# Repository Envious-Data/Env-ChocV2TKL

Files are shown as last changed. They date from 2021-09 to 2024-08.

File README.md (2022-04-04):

# Env-ChocV2TKL
A Compact TKL layout utilizing Choc V2s and a Raspberry Pi Pico

### What this is
This is an experiment/concept, Ive been wanting a choc keyboard for a while but finding keycaps for choc V1s is rather difficult. There are also almost no ISO Keycap sets that would go on a TKL HOWEVER! it appears Choc V2s are more alike cherry LP switches which fit normal MX keycaps, they have a different footprint to Choc V1s and MX style switches (which Cherry LP is also not like normal MX).

###
feel free to steal the Choc V2 footprint out of here but, I made it by modifying the choc V1 footprint and just adjusted/resized a couple bits to fit but im not wholly sure if its correct.. well it should be as per the dimentions listed by Kailh.

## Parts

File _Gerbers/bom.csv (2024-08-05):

Designator | Footprint | Quantity | Value | LCSC Part #
D1, D2 | 0805 | 2 | 0805 LED
D_0, D_1, D_10, D_11, D_12, D_13, D_14, D_15, D_16, D_17, D_18, D_19, D_2, D_20, D_21, D_22, D_23, D_24, D_25, D_26, D_27, D_28, D_29, D_3, D_30, D_31, D_32, D_33, D_34, D_35, D_36, D_37, D_38, D_39, D_4, D_40, D_41, D_42, D_43, D_44, D_45, D_46, D_47, D_48, D_49, D_5, D_50, D_51, D_52, D_53, D_54, D_55, D_56, D_57, D_58, D_59, D_6, D_60, D_61, D_62, D_63, D_64, D_65, D_66, D_67, D_68, D_69, D_7, D_70, D_71, D_72, D_73, D_74, D_75, D_76, D_77, D_78, D_79, D_8, D_80, D_81, D_82, D_83, D_84, D_85, D_86, D_87, D_9 | D_SOD-123 | 88 | 1N4148W
H1, H2, H3, H4, H5, H6 | MountingHole_3.2mm_M3 | 6 | MountingHole_Pad
J1 | USB_C_TYPE-C-31-M-14 | 1 | Type-c-31-m-14
K_0, K_1, K_10, K_11, K_12, K_13, K_14, K_15, K_16, K_17, K_18, K_19, K_2, K_20, K_21, K_22, K_23, K_24, K_25, K_26, K_27, K_28, K_29, K_3, K_30, K_31, K_32, K_33, K_34, K_35, K_36, K_37, K_38, K_39, K_4, K_40, K_41, K_42, K_43, K_44, K_45, K_46, K_47, K_48, K_49, K_5, K_50, K_51, K_52, K_53, K_54, K_55, K_56, K_57, K_58, K_59, K_6, K_60, K_61, K_62, K_63, K_64, K_65, K_66, K_67, K_68, K_69, K_7, K_70, K_71, K_72, K_73, K_74, K_75, K_76, K_77, K_78, K_79, K_8, K_80, K_81, K_82, K_83, K_84, K_85, K_86, K_87, K_9 | SW_Kailh_Choc_V2 | 88 | KEYSW
R1, R2 | 0402 | 2 | 0402 470r
R5, R6 | 0805 | 2 | 5.1K 0805
RPI1 | RPi_Pico_SMD_TH_MODIFIED | 1 | Pico
SW101, SW102 | Panasonic_EVQPUL_EVQPUC | 2 | EVQPU

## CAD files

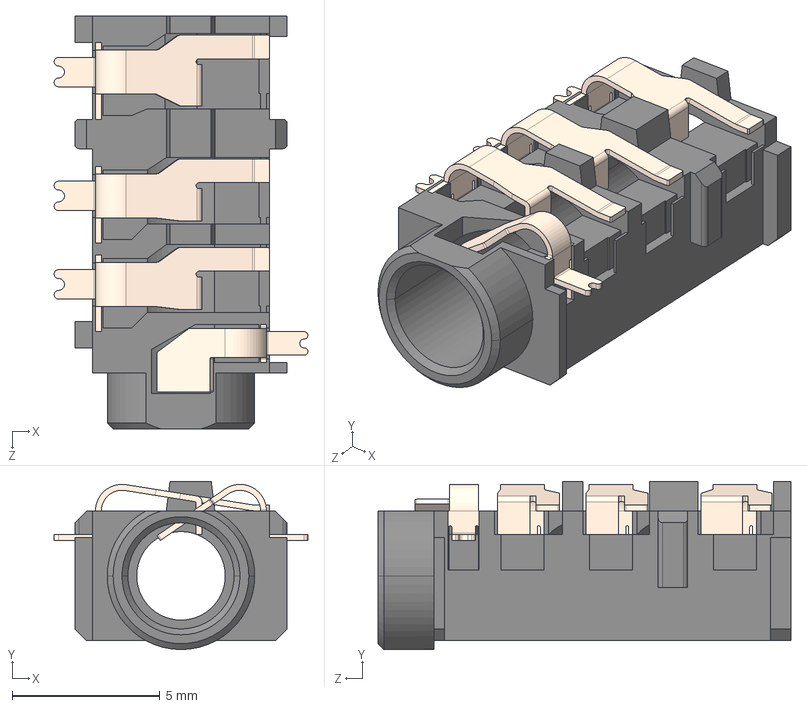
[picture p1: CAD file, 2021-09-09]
PCB Design/Footprints/Keebio-Parts.pretty-master/3dmodels/CUI_SJ-43614-SMT-TR.step
8.60 x 5.70 x 14.0 mm

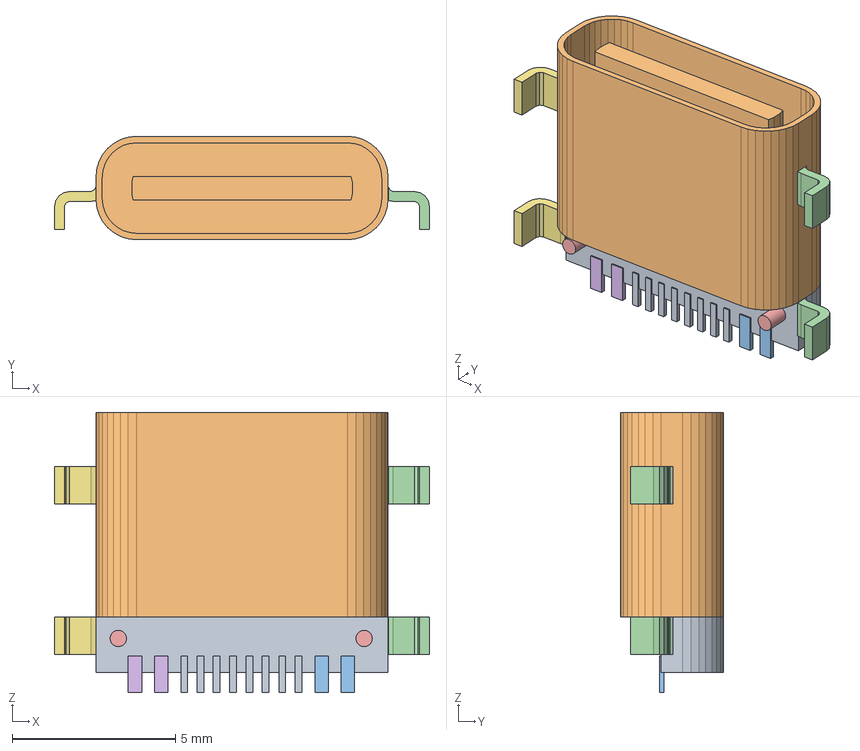
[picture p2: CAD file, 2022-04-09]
PCB Design/Footprints/TYPE-C-31-M-14.step
11.5 x 3.16 x 8.58 mm

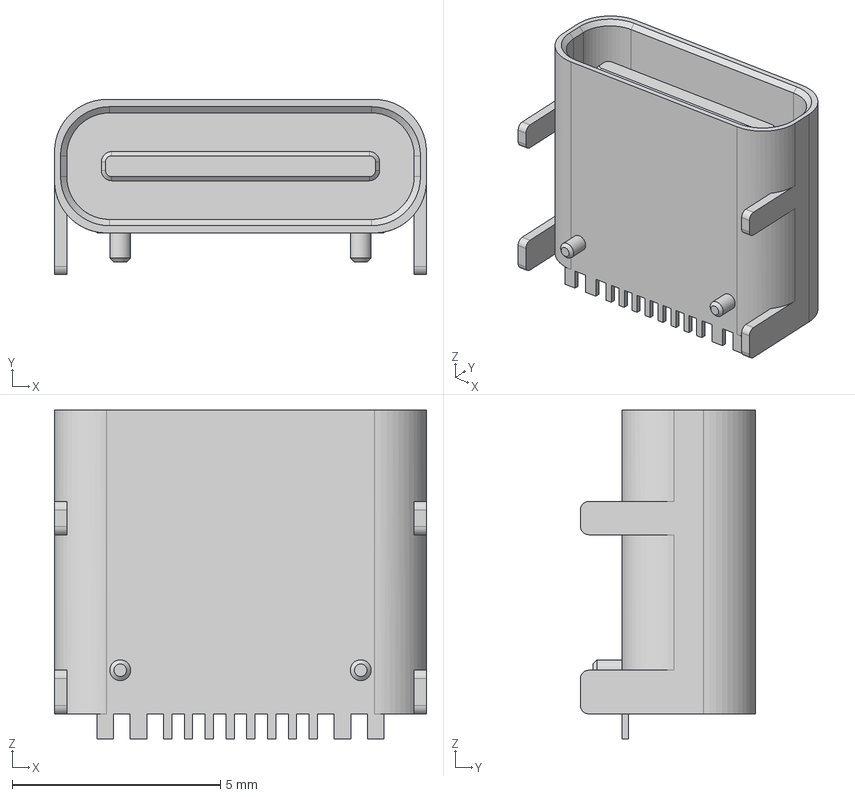
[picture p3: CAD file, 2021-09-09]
PCB Design/Footprints/Keebio-Parts.pretty-master/3dmodels/HRO TYPE-C-31-M-12.step
8.94 x 4.21 x 7.90 mm

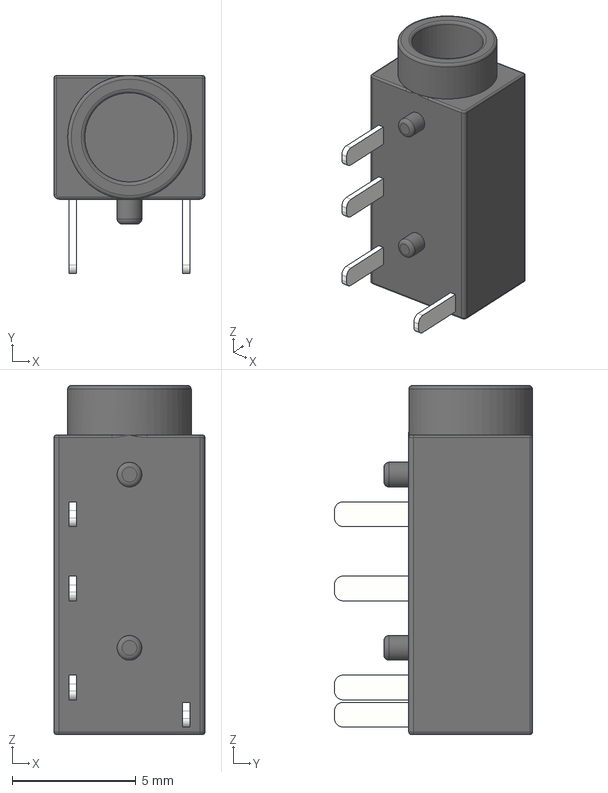
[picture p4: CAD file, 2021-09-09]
PCB Design/Footprints/Keebio-Parts.pretty-master/3dmodels/PJ-320A.step
6.10 x 8.00 x 14.1 mm

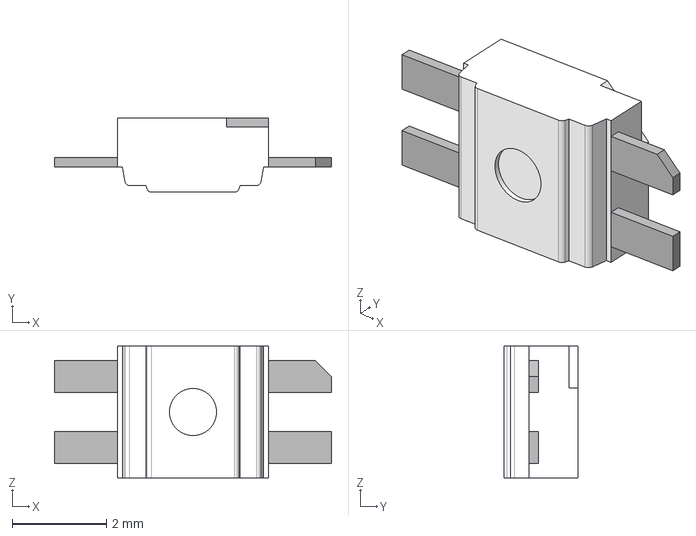
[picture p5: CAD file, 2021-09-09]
PCB Design/Footprints/Keebio-Parts.pretty-master/3dmodels/SK6812MINI-E v1.step
5.88 x 1.58 x 2.80 mm

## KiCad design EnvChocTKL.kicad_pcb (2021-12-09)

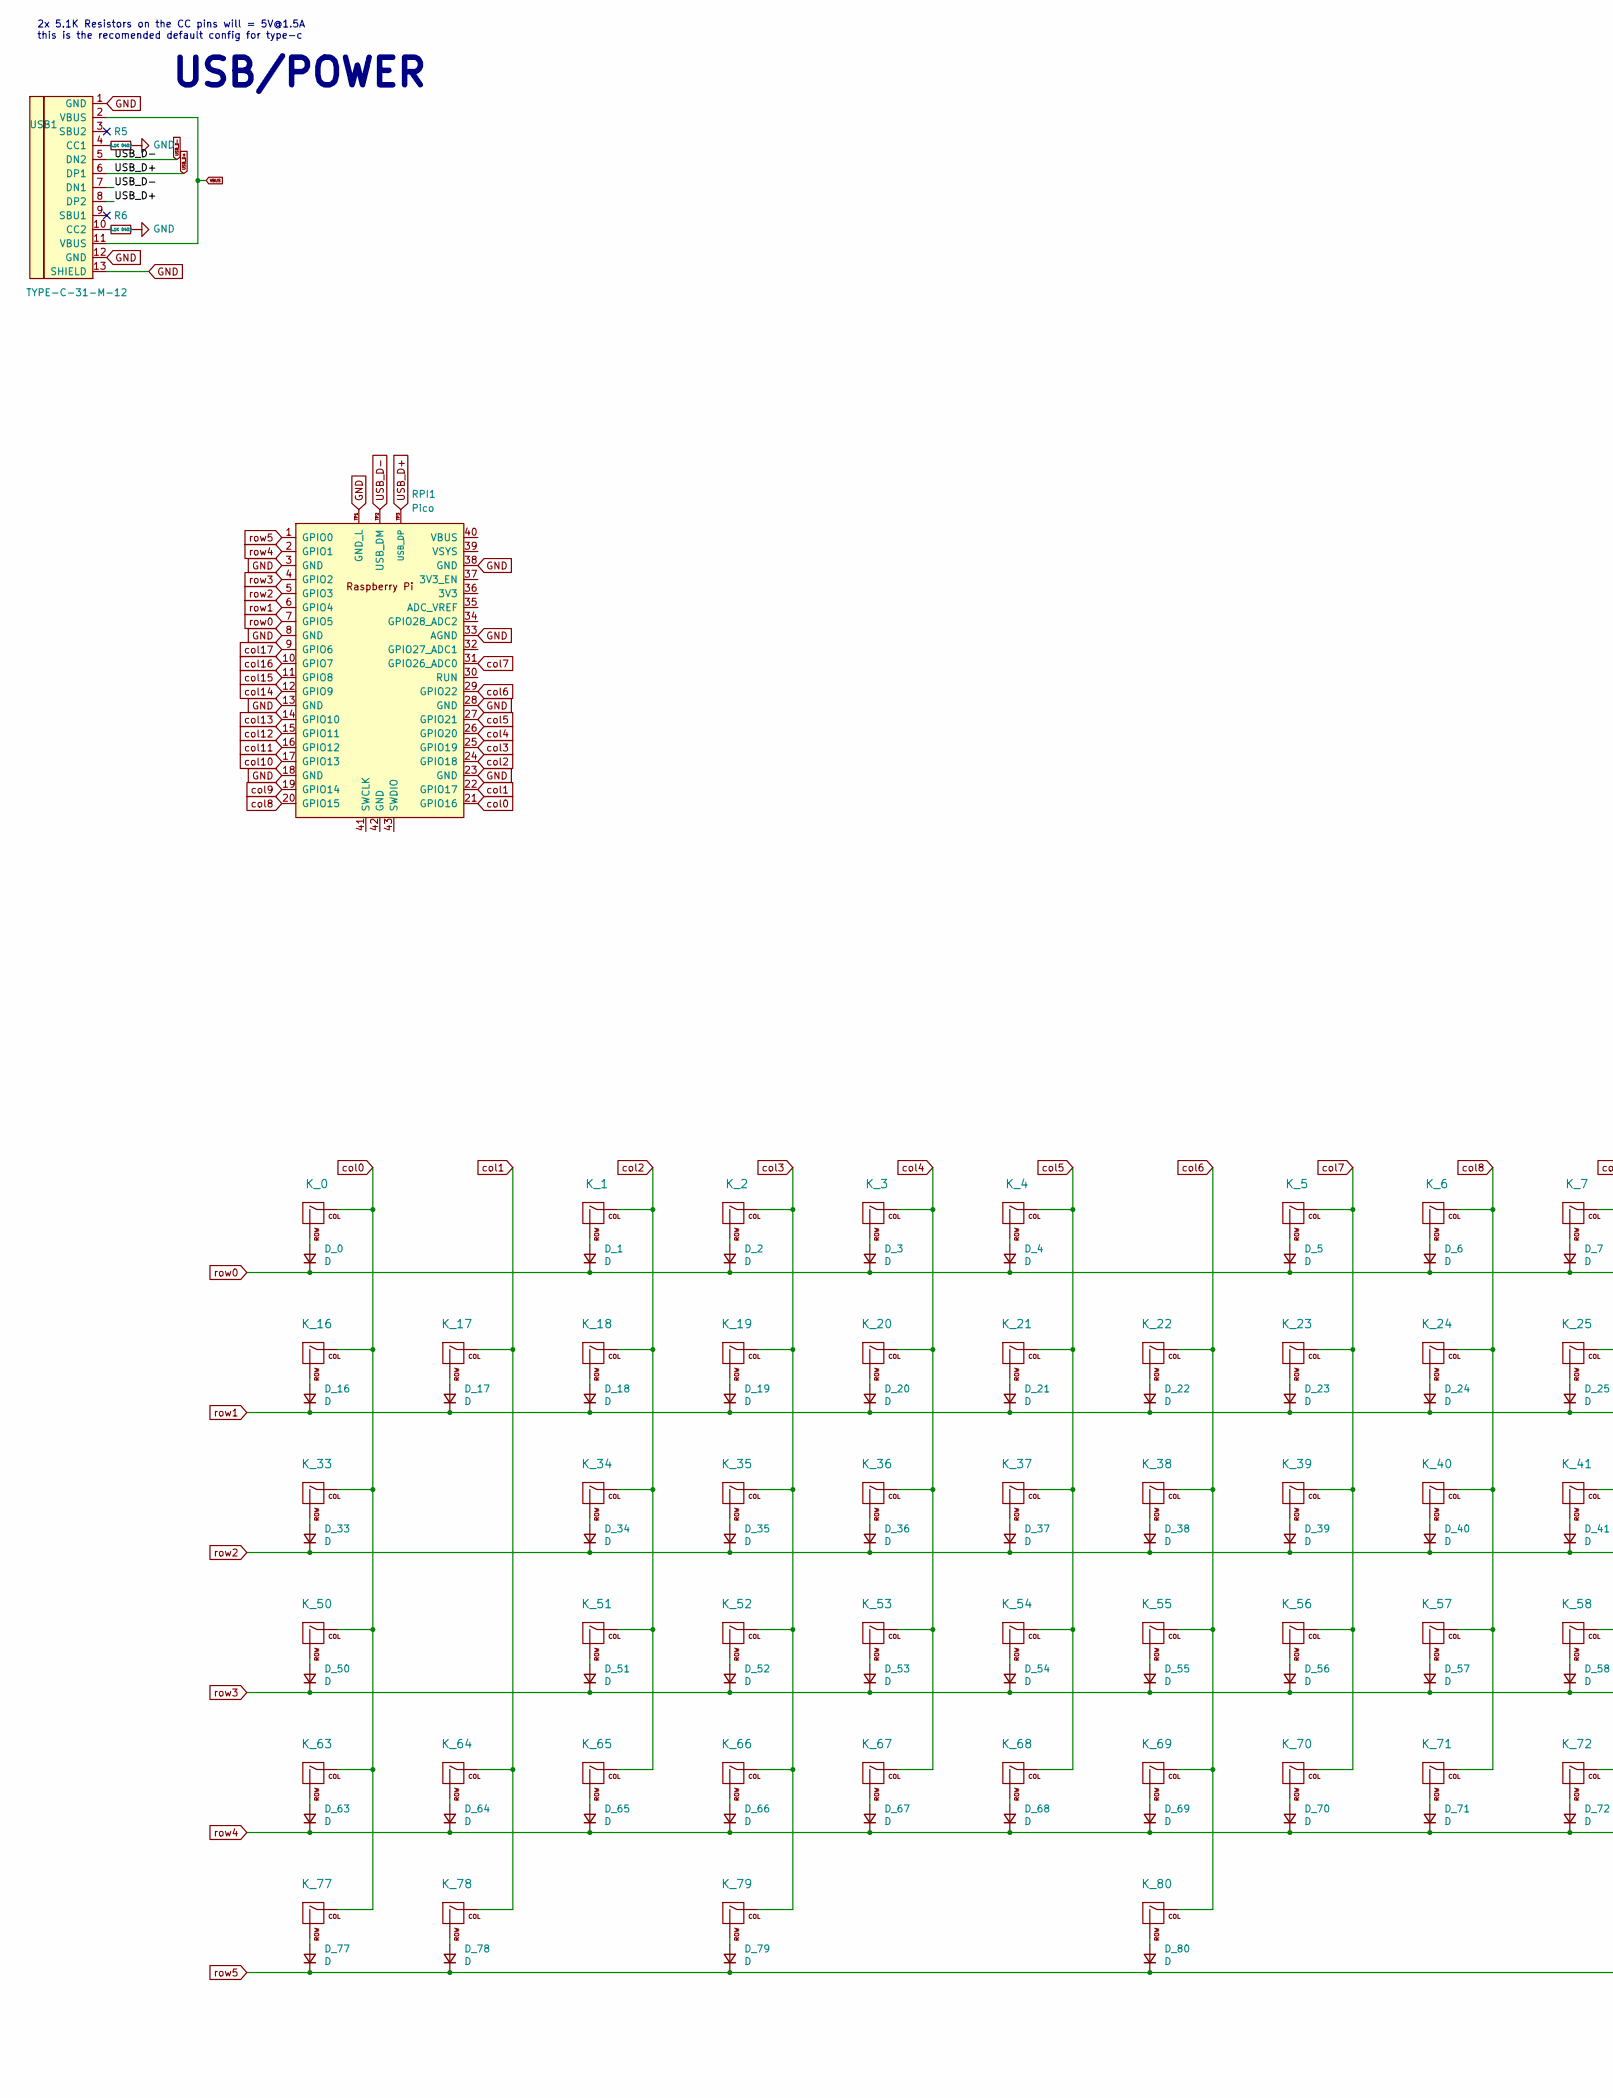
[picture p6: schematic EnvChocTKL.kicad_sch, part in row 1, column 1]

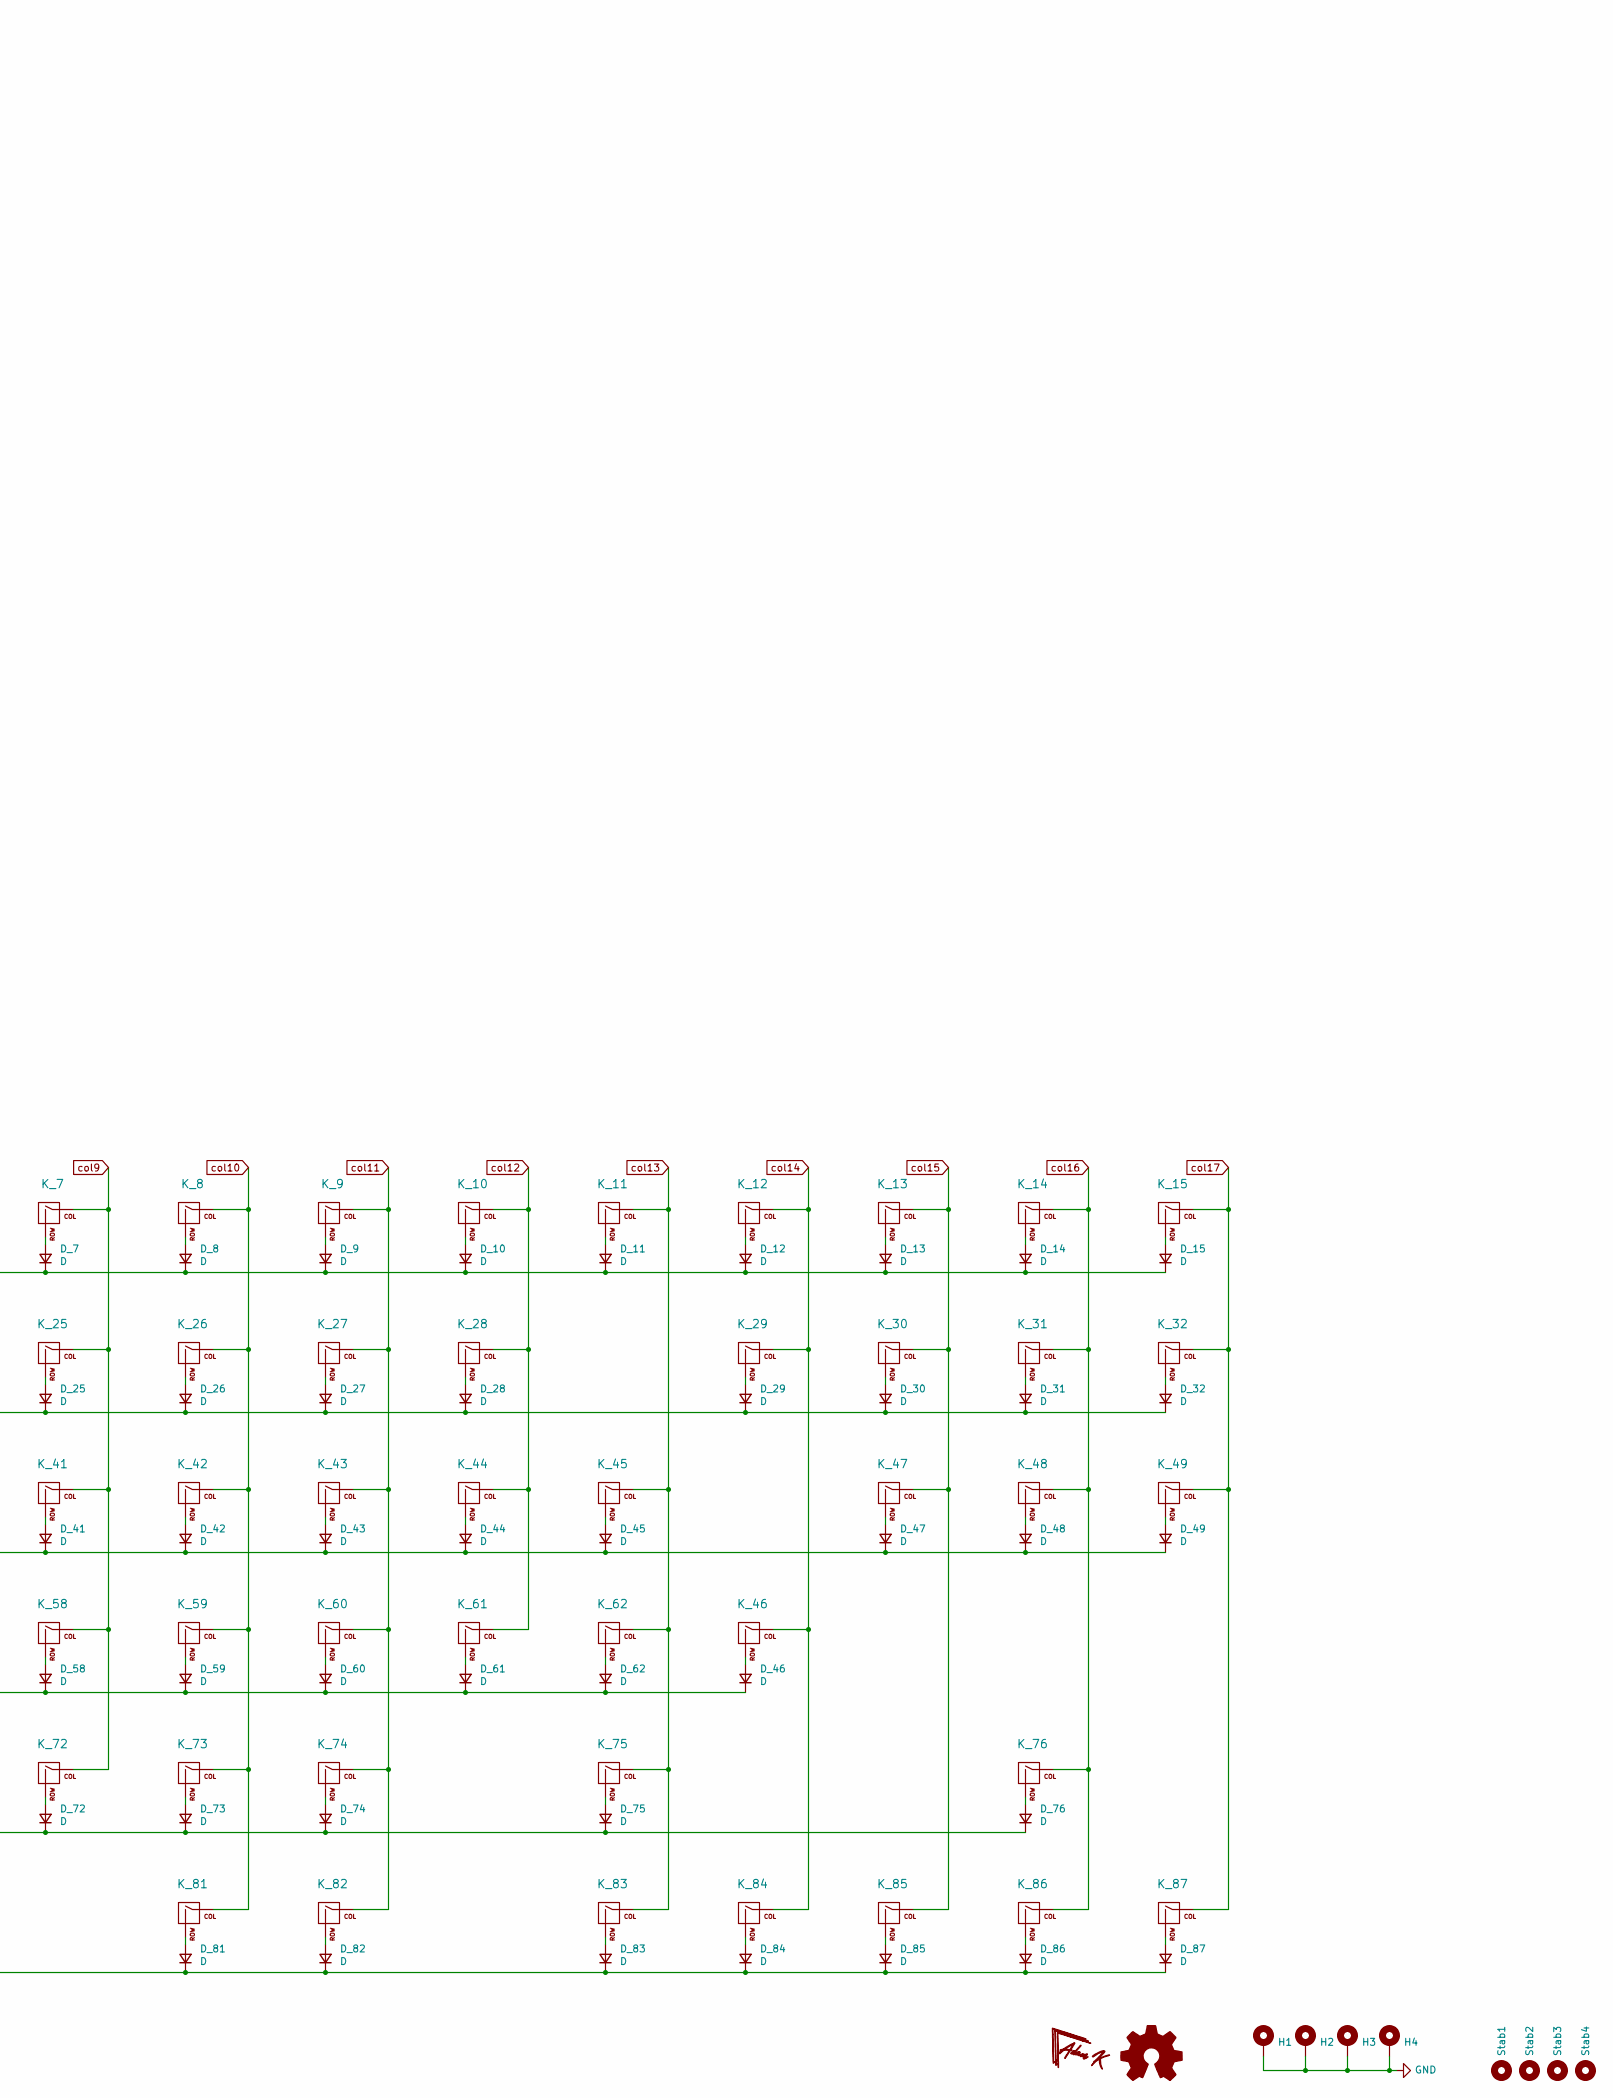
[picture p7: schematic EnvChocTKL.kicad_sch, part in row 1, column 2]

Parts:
D_0, D_1, D_2, D_3, D_4, D_5, D_6, D_7, D_8, D_9, D_10, D_11, D_12, D_13, D_14, D_15, D_16, D_17, D_18, D_19, D_20, D_21, D_22, D_23, D_24, D_25, D_26, D_27, D_28, D_29, D_30, D_31, D_32, D_33, D_34, D_35, D_36, D_37, D_38, D_39, D_40, D_41, D_42, D_43, D_44, D_45, D_46, D_47, D_48, D_49, D_50, D_51, D_52, D_53, D_54, D_55, D_56, D_57, D_58, D_59, D_60, D_61, D_62, D_63, D_64, D_65, D_66, D_67, D_68, D_69, D_70, D_71, D_72, D_73, D_74, D_75, D_76, D_77, D_78, D_79, D_80, D_81, D_82, D_83, D_84, D_85, D_86, D_87: D; D_SOD-123
H1, H2, H3, H4: MountingHole_Pad; MountingHole_2.5mm_Pad
K_0, K_1, K_2, K_3, K_4, K_5, K_6, K_7, K_8, K_9, K_10, K_11, K_12, K_13, K_14, K_15, K_16, K_17, K_18, K_19, K_20, K_21, K_22, K_23, K_24, K_25, K_26, K_27, K_28, K_29, K_30, K_31, K_32, K_33, K_34, K_35, K_36, K_37, K_38, K_39, K_40, K_41, K_42, K_43, K_44, K_45, K_46, K_47, K_48, K_49, K_50, K_51, K_52, K_53, K_54, K_55, K_56, K_57, K_58, K_59, K_60, K_61, K_62, K_63, K_64, K_65, K_66, K_67, K_68, K_69, K_70, K_71, K_72, K_73, K_74, K_75, K_76, K_77, K_78, K_79, K_80, K_81, K_82, K_83, K_84, K_85, K_86, K_87: KEYSW; SW_Kailh_Choc_V2
R5, R6: 5.1K 0402; R_0402_1005Metric
RPI1: Pico; RPi_Pico_SMD_TH_MODIFIED
Stab1, Stab2, Stab3: MountingHole_Pad; Stabilizer_Cherry_MX_2u
Stab4: MountingHole_Pad; Stabilizer_Cherry_MX_6.25u
USB1: TYPE-C-31-M-12; HRO-TYPE-C-31-M-12; LCSC C165948

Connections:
GND: H1.1, H2.1, H3.1, H4.1, R5.1, R6.1; also elsewhere on the board
unnamed: D_0.2 (A), K_0.2 (ROW)
unnamed: D_1.2 (A), K_1.2 (ROW)
unnamed: D_2.2 (A), K_2.2 (ROW)
unnamed: D_3.2 (A), K_3.2 (ROW)
unnamed: D_4.2 (A), K_4.2 (ROW)
unnamed: D_5.2 (A), K_5.2 (ROW)
unnamed: D_6.2 (A), K_6.2 (ROW)
unnamed: D_7.2 (A), K_7.2 (ROW)
unnamed: D_8.2 (A), K_8.2 (ROW)
unnamed: D_9.2 (A), K_9.2 (ROW)
unnamed: D_10.2 (A), K_10.2 (ROW)
unnamed: D_11.2 (A), K_11.2 (ROW)
unnamed: D_12.2 (A), K_12.2 (ROW)
unnamed: D_13.2 (A), K_13.2 (ROW)
unnamed: D_14.2 (A), K_14.2 (ROW)
unnamed: D_15.2 (A), K_15.2 (ROW)
unnamed: D_16.2 (A), K_16.2 (ROW)
unnamed: D_17.2 (A), K_17.2 (ROW)
unnamed: D_18.2 (A), K_18.2 (ROW)
unnamed: D_19.2 (A), K_19.2 (ROW)
unnamed: D_20.2 (A), K_20.2 (ROW)
unnamed: D_21.2 (A), K_21.2 (ROW)
unnamed: D_22.2 (A), K_22.2 (ROW)
unnamed: D_23.2 (A), K_23.2 (ROW)
unnamed: D_24.2 (A), K_24.2 (ROW)
unnamed: D_25.2 (A), K_25.2 (ROW)
unnamed: D_26.2 (A), K_26.2 (ROW)
unnamed: D_27.2 (A), K_27.2 (ROW)
unnamed: D_28.2 (A), K_28.2 (ROW)
unnamed: D_29.2 (A), K_29.2 (ROW)
unnamed: D_30.2 (A), K_30.2 (ROW)
unnamed: D_31.2 (A), K_31.2 (ROW)
unnamed: D_32.2 (A), K_32.2 (ROW)
unnamed: D_33.2 (A), K_33.2 (ROW)
unnamed: D_34.2 (A), K_34.2 (ROW)
unnamed: D_35.2 (A), K_35.2 (ROW)
unnamed: D_36.2 (A), K_36.2 (ROW)
unnamed: D_37.2 (A), K_37.2 (ROW)
unnamed: D_38.2 (A), K_38.2 (ROW)
unnamed: D_39.2 (A), K_39.2 (ROW)
unnamed: D_40.2 (A), K_40.2 (ROW)
unnamed: D_41.2 (A), K_41.2 (ROW)
unnamed: D_42.2 (A), K_42.2 (ROW)
unnamed: D_43.2 (A), K_43.2 (ROW)
unnamed: D_44.2 (A), K_44.2 (ROW)
unnamed: D_45.2 (A), K_45.2 (ROW)
unnamed: D_46.2 (A), K_46.2 (ROW)
unnamed: D_47.2 (A), K_47.2 (ROW)
unnamed: D_48.2 (A), K_48.2 (ROW)
unnamed: D_49.2 (A), K_49.2 (ROW)
unnamed: D_50.2 (A), K_50.2 (ROW)
unnamed: D_51.2 (A), K_51.2 (ROW)
unnamed: D_52.2 (A), K_52.2 (ROW)
unnamed: D_53.2 (A), K_53.2 (ROW)
unnamed: D_54.2 (A), K_54.2 (ROW)
unnamed: D_55.2 (A), K_55.2 (ROW)
unnamed: D_56.2 (A), K_56.2 (ROW)
unnamed: D_57.2 (A), K_57.2 (ROW)
unnamed: D_58.2 (A), K_58.2 (ROW)
unnamed: D_59.2 (A), K_59.2 (ROW)
unnamed: D_60.2 (A), K_60.2 (ROW)
unnamed: D_61.2 (A), K_61.2 (ROW)
unnamed: D_62.2 (A), K_62.2 (ROW)
unnamed: D_63.2 (A), K_63.2 (ROW)
unnamed: D_64.2 (A), K_64.2 (ROW)
unnamed: D_65.2 (A), K_65.2 (ROW)
unnamed: D_66.2 (A), K_66.2 (ROW)
unnamed: D_67.2 (A), K_67.2 (ROW)
unnamed: D_68.2 (A), K_68.2 (ROW)
unnamed: D_69.2 (A), K_69.2 (ROW)
unnamed: D_70.2 (A), K_70.2 (ROW)
unnamed: D_71.2 (A), K_71.2 (ROW)
unnamed: D_72.2 (A), K_72.2 (ROW)
unnamed: D_73.2 (A), K_73.2 (ROW)
unnamed: D_74.2 (A), K_74.2 (ROW)
unnamed: D_75.2 (A), K_75.2 (ROW)
unnamed: D_76.2 (A), K_76.2 (ROW)
unnamed: D_77.2 (A), K_77.2 (ROW)
unnamed: D_78.2 (A), K_78.2 (ROW)
unnamed: D_79.2 (A), K_79.2 (ROW)
unnamed: D_80.2 (A), K_80.2 (ROW)
unnamed: D_81.2 (A), K_81.2 (ROW)
unnamed: D_82.2 (A), K_82.2 (ROW)
unnamed: D_83.2 (A), K_83.2 (ROW)
unnamed: D_84.2 (A), K_84.2 (ROW)
unnamed: D_85.2 (A), K_85.2 (ROW)
unnamed: D_86.2 (A), K_86.2 (ROW)
unnamed: D_87.2 (A), K_87.2 (ROW)
unnamed: R5.2, USB1.4 (CC1)
unnamed: R6.2, USB1.10 (CC2)
unnamed: RPI1.3 (GND), RPI1.8 (GND), RPI1.13 (GND), RPI1.18 (GND), RPI1.23 (GND), RPI1.28 (GND), RPI1.33 (AGND), RPI1.38 (GND), RPI1.TP1 (GND_L), USB1.1 (GND), USB1.12 (GND), USB1.13 (SHIELD)
unnamed: RPI1.TP2 (USB_DM), USB1.5 (DN2), USB1.7 (DN1)
unnamed: RPI1.TP3 (USB_DP), USB1.6 (DP1), USB1.8 (DP2)
unnamed: USB1.2 (VBUS), USB1.11 (VBUS)
col0: K_0.1 (COL), K_16.1 (COL), K_33.1 (COL), K_50.1 (COL), K_63.1 (COL), K_77.1 (COL), RPI1.21 (GPIO16); also elsewhere on the board
col1: K_17.1 (COL), K_64.1 (COL), K_78.1 (COL), RPI1.22 (GPIO17); also elsewhere on the board
col2: K_1.1 (COL), K_18.1 (COL), K_34.1 (COL), K_51.1 (COL), K_65.1 (COL), RPI1.24 (GPIO18); also elsewhere on the board
col3: K_2.1 (COL), K_19.1 (COL), K_35.1 (COL), K_52.1 (COL), K_66.1 (COL), K_79.1 (COL), RPI1.25 (GPIO19); also elsewhere on the board
col4: K_3.1 (COL), K_20.1 (COL), K_36.1 (COL), K_53.1 (COL), K_67.1 (COL), RPI1.26 (GPIO20); also elsewhere on the board
col5: K_4.1 (COL), K_21.1 (COL), K_37.1 (COL), K_54.1 (COL), K_68.1 (COL), RPI1.27 (GPIO21); also elsewhere on the board
col6: K_22.1 (COL), K_38.1 (COL), K_55.1 (COL), K_69.1 (COL), K_80.1 (COL), RPI1.29 (GPIO22); also elsewhere on the board
col7: K_5.1 (COL), K_23.1 (COL), K_39.1 (COL), K_56.1 (COL), K_70.1 (COL), RPI1.31 (GPIO26_ADC0); also elsewhere on the board
col8: K_6.1 (COL), K_24.1 (COL), K_40.1 (COL), K_57.1 (COL), K_71.1 (COL), RPI1.20 (GPIO15); also elsewhere on the board
col9: K_7.1 (COL), K_25.1 (COL), K_41.1 (COL), K_58.1 (COL), K_72.1 (COL), RPI1.19 (GPIO14); also elsewhere on the board
col10: K_8.1 (COL), K_26.1 (COL), K_42.1 (COL), K_59.1 (COL), K_73.1 (COL), K_81.1 (COL), RPI1.17 (GPIO13); also elsewhere on the board
col11: K_9.1 (COL), K_27.1 (COL), K_43.1 (COL), K_60.1 (COL), K_74.1 (COL), K_82.1 (COL), RPI1.16 (GPIO12); also elsewhere on the board
col12: K_10.1 (COL), K_28.1 (COL), K_44.1 (COL), K_61.1 (COL), RPI1.15 (GPIO11); also elsewhere on the board
col13: K_11.1 (COL), K_45.1 (COL), K_62.1 (COL), K_75.1 (COL), K_83.1 (COL), RPI1.14 (GPIO10); also elsewhere on the board
col14: K_12.1 (COL), K_29.1 (COL), K_46.1 (COL), K_84.1 (COL), RPI1.12 (GPIO9); also elsewhere on the board
col15: K_13.1 (COL), K_30.1 (COL), K_47.1 (COL), K_85.1 (COL), RPI1.11 (GPIO8); also elsewhere on the board
col16: K_14.1 (COL), K_31.1 (COL), K_48.1 (COL), K_76.1 (COL), K_86.1 (COL), RPI1.10 (GPIO7); also elsewhere on the board
col17: K_15.1 (COL), K_32.1 (COL), K_49.1 (COL), K_87.1 (COL), RPI1.9 (GPIO6); also elsewhere on the board
row0: D_0.1 (K), D_1.1 (K), D_2.1 (K), D_3.1 (K), D_4.1 (K), D_5.1 (K), D_6.1 (K), D_7.1 (K), D_8.1 (K), D_9.1 (K), D_10.1 (K), D_11.1 (K), D_12.1 (K), D_13.1 (K), D_14.1 (K), D_15.1 (K), RPI1.7 (GPIO5); also elsewhere on the board
row1: D_16.1 (K), D_17.1 (K), D_18.1 (K), D_19.1 (K), D_20.1 (K), D_21.1 (K), D_22.1 (K), D_23.1 (K), D_24.1 (K), D_25.1 (K), D_26.1 (K), D_27.1 (K), D_28.1 (K), D_29.1 (K), D_30.1 (K), D_31.1 (K), D_32.1 (K), RPI1.6 (GPIO4); also elsewhere on the board
row2: D_33.1 (K), D_34.1 (K), D_35.1 (K), D_36.1 (K), D_37.1 (K), D_38.1 (K), D_39.1 (K), D_40.1 (K), D_41.1 (K), D_42.1 (K), D_43.1 (K), D_44.1 (K), D_45.1 (K), D_47.1 (K), D_48.1 (K), D_49.1 (K), RPI1.5 (GPIO3); also elsewhere on the board
row3: D_46.1 (K), D_50.1 (K), D_51.1 (K), D_52.1 (K), D_53.1 (K), D_54.1 (K), D_55.1 (K), D_56.1 (K), D_57.1 (K), D_58.1 (K), D_59.1 (K), D_60.1 (K), D_61.1 (K), D_62.1 (K), RPI1.4 (GPIO2); also elsewhere on the board
row4: D_63.1 (K), D_64.1 (K), D_65.1 (K), D_66.1 (K), D_67.1 (K), D_68.1 (K), D_69.1 (K), D_70.1 (K), D_71.1 (K), D_72.1 (K), D_73.1 (K), D_74.1 (K), D_75.1 (K), D_76.1 (K), RPI1.2 (GPIO1); also elsewhere on the board
row5: D_77.1 (K), D_78.1 (K), D_79.1 (K), D_80.1 (K), D_81.1 (K), D_82.1 (K), D_83.1 (K), D_84.1 (K), D_85.1 (K), D_86.1 (K), D_87.1 (K), RPI1.1 (GPIO0); also elsewhere on the board

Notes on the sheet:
USB/POWER
2x 5.1K Resistors on the CC pins will = 5V@1.5A this is the recomended default config for type-c

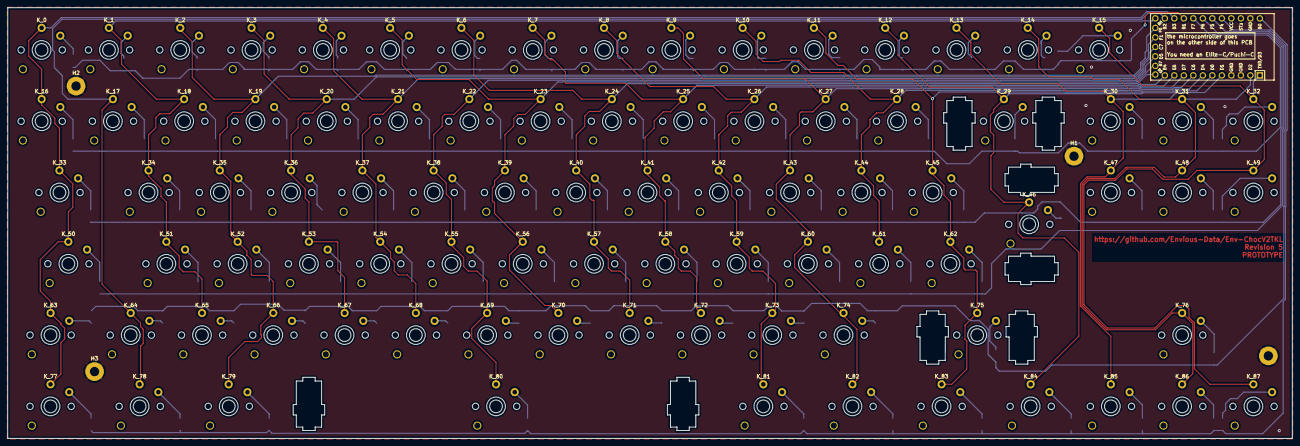
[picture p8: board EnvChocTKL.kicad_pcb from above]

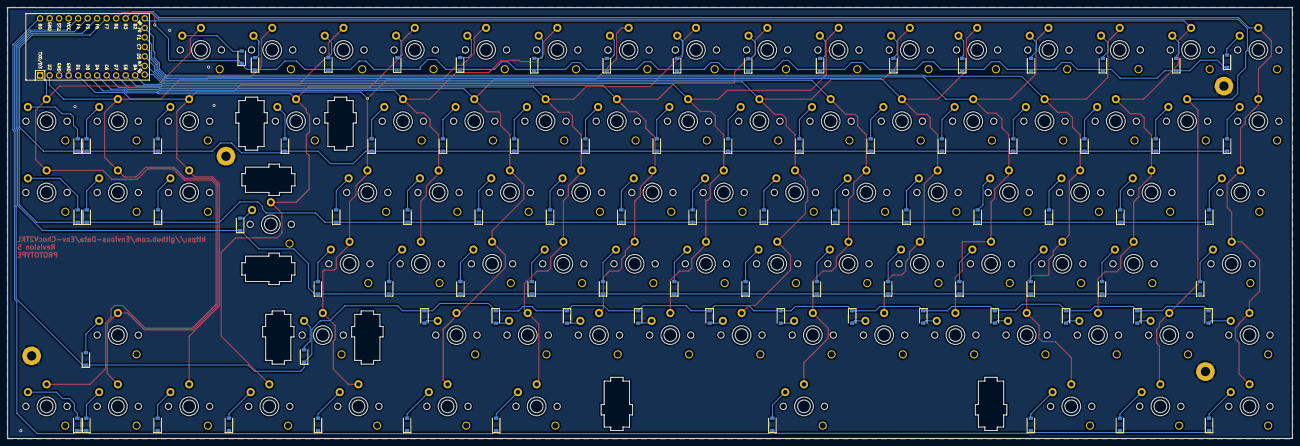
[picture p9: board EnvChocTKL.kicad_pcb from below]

Board: 2 copper layers, 343.3 x 115.1 mm, 181 parts (89 on the bottom side), 113 nets.

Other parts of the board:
U1: EliteC; Elite-C

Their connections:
GND: U1.3, U1.4, U1.23; also elsewhere on the board
col0: U1.15; also elsewhere on the board
col1: U1.14; also elsewhere on the board
col2: U1.13; also elsewhere on the board
col3: U1.29; also elsewhere on the board
col4: U1.28; also elsewhere on the board
col5: U1.27; also elsewhere on the board
col6: U1.26; also elsewhere on the board
col7: U1.25; also elsewhere on the board
col8: U1.12; also elsewhere on the board
col9: U1.11; also elsewhere on the board
col10: U1.10; also elsewhere on the board
col11: U1.9; also elsewhere on the board
col12: U1.8; also elsewhere on the board
col13: U1.7; also elsewhere on the board
col14: U1.6; also elsewhere on the board
col15: U1.5; also elsewhere on the board
col16: U1.2; also elsewhere on the board
col17: U1.1; also elsewhere on the board
row0: U1.16; also elsewhere on the board
row1: U1.17; also elsewhere on the board
row2: U1.18; also elsewhere on the board
row3: U1.19; also elsewhere on the board
row4: U1.20; also elsewhere on the board
row5: U1.24; also elsewhere on the board

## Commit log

2021-09-11 added mount holes, a few silkscreen marks and generated revision 0 gerber
    [EnvChocTKL.kicad_pcb, EnvChocTKL.sch, EnvChocTKL_bom_jlc.csv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]
2021-09-11 forgot to save changes to pcbnew
    [EnvChocTKL.kicad_pcb]
2021-09-11 Corrected some errors and generated a fixed gerber
    [EnvChocTKL.kicad_pcb]
2021-09-19 updated Choc V2 footprint
2021-11-19 swapped footprint to sort of fit chocV1 as well and corrected all DRC errors
    [EnvChocTKL.kicad_pcb]
2021-11-22 replaced stabs with cutouts for lower profile mounting and fixed issues relating to such, generated updated gerber
    [EnvChocTKL.kicad_pcb]
2021-11-22 changed cutout shape and generated another gerber
    [EnvChocTKL.kicad_pcb]
2021-11-22 moved MCU and redid a bunch of traces
    [EnvChocTKL.kicad_pcb, EnvChocTKL.sch]
2021-11-22 added mount holes and adjusted some traces in relation
    [EnvChocTKL.kicad_pcb]
2021-11-22 updated silkscreen and ran cleanup
    [EnvChocTKL.kicad_pcb]
2021-11-25 adjusted cutouts and related, also orderd this version via jlc.
    [EnvChocTKL.kicad_pcb]
2021-11-26 DERP! - missing trace, D12 to pin2 of Switch 12
    [EnvChocTKL.kicad_pcb]
2021-12-09 fixed issues with footprint and required board changes + updated gerber
    [EnvChocTKL.kicad_pcb, EnvChocTKL.sch, EnvChocTKL_bom_jlc.csv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]
2021-12-09 adjusted couple traces and sorted out revision
    [EnvChocTKL.kicad_pcb]
2021-12-26 refined design a bit by spacing function row and nav cluster apart just a bit, moved some other parts and started work on stabilizer footprints
    [EnvChocTKL.kicad_sch]
2022-01-11 some changes I forgot to commit.
    [EnvChocTKL_bom_jlc.csv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]
2022-02-23 converted MCU from elite-c to onboard RP2040
    [EnvChocTKL.kicad_sch]
2022-02-23 ground unconnected for some deoupling capacitors
2022-02-24 fixed doubled hole on footprint and adjusted board settings to comply with JLCPCB Capabilities.
2022-03-07 flipped MCU to other side
    might optimize the space usage of the MCU so I can have a more normal top row.
    [EnvChocTKL.kicad_sch]
2022-03-07 generated updated Gerbers and made appropriate part changes
    [EnvChocTKL.csv, EnvChocTKL.kicad_sch, EnvChocTKL_bom_jlc.csv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]
2022-03-09 swapped flash for lager SOIC-8 and removed some parts.
    [EnvChocTKL.kicad_sch]
2022-03-12 IMPORTANT FIX
    for some reason a lot of the switches were slightly misaligned to MX spacing and also added cutouts for Choc stabs on Eco.User to be exported as DXF for whatever.
    [EnvChocTKL.csv, EnvChocTKL.kicad_sch, EnvChocTKL_bom_jlc.csv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]
2022-04-01 Swapped MCU from onboard RP2040 to RPI PICO
    [EnvChocTKL.kicad_sch]
2022-04-03 modified PCB design to be cheaper, 0.15mm thick tracks, 0.2mm spacing, 0.8/0.4mm vias.
2022-04-04 updated Readme and file organization
    [CUI_SJ-43614-SMT-TR.step, EnvChocTKL.kicad_sch, EnvChocTKL.sch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]
2022-04-09 added mid-mount type-c port, swapped onboard MCU for pico and also couple more mount holes, various other adjustments i.e backplate n stuff
    [EnvChocTKL.kicad_sch, EnvChocTKL_bom_jlc.csv, TYPE-C-31-M-14.step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]
2022-04-09 added mount hole cutouts to user eco layers.
2022-05-18 made usb pin cutout larger for ease of soldering.
2022-06-07 generated updated gerber
    [EnvChocTKL.kicad_sch, EnvChocTKL_bom_jlc.csv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]
2022-06-18 modified footprint to have TP6 and added reset and bootsel buttons
    [EnvChocTKL.kicad_sch]
2022-12-08 generated gerber and 3d model
    [EnvChocTKL-User_Eco2.dxf, EnvChocTKL_bom_jlc.csv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]
2022-12-16 made backplate and switch plate as well as adjusted main pcb mount holes for standoffs
    [EnvChocTKL-BackPlate.kicad_pcb, EnvChocTKL-BackPlate.kicad_sch, EnvChocTKL-SwitchPlate.kicad_pcb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]
2023-01-09 moved gerbers to their own folder + removed old versions since git will record that.
    [EnvChocTKL_bom_jlc.csv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]
2024-07-27 checks and preparation to order
    [EnvChocTKL-BackPlate.kicad_pcb, EnvChocTKL-SwitchPlate.kicad_pcb, EnvChocTKL.kicad_sch]
2024-08-05 Generated production files
    [EnvChocTKL-BackPlate.kicad_pcb, EnvChocTKL_bom_jlc.csv, bom.csv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]
